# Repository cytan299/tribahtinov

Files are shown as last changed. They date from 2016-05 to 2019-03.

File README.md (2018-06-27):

<p align="right">Language: English, <a href="translations/README_JA.md">Japanese</a></p>

# A Tri-Bahtinov Mask for Aiding Collimation and Focusing of Schmidt Cassegrain, Ritchey Chretien and Newtonian Telescopes

## Introduction

In my opinion, the Bahtinov mask is one of the most useful inventions
for astrophotography. The traditional use of a Bahtinov mask is for
focusing a telescope only and is not used for collimation of reflector
type telescopes like SCTs, RCs and Newtonians.
For collimating a reflector, the method that is commonly used is the
[Airy disk method](http://www.astrophoto.fr/collim.html). I have found
this method to be quite onerous because

* due to atmospherics at my observation location, I have never been able
to see a really clear diffraction pattern of the defocused star or Airy disk. 
* when I adjust the collimating screws to centre the doughnut hole, my
  judgement is rather arbitrary and not as objective as it should
  be. I think my overly optimistic judgement of the diffraction pattern
  makes this method a collimation challenge for me.

And thus, these two reasons motivated me to create a less judgemental
way for collimation.

## The idea

Since the standard Bahtinov mask is such a useful tool for focusing, I
thought that there must be a way to use it for collimation as
well. My idea when applied to an SCT is as follows:

For an SCT, that is well collimated, I would expect that the path
length travelled by light rays from the primary mirror reflected to
the secondary mirror and then reflected to the image plane should all
be the same. However, if the SCT is not collimated then the light rays
do not all have the same path lengths. The effect is that focus can
only be established at one location on the image plane, while focus is
not achieved at other locations.

Therefore, for an uncollimated SCT, while I can achieve perfect
Bahtinov diffraction spikes with one orientation of the Bahtinov mask,
the diffractions spikes will not be perfect for other
orientations. Thus, in my opinion, the most natural way to
simultaneously measure the focus for different orientations of the
Bahtinov mask is to make a mask that has multiple orientations
already built in.

## Tri-Bahtinov mask

For an SCT, the secondary mirror has three adjustment
screws. Therefore, the most obvious way to me is to have three
Bahtinov masks designed into the mask. Thus, my idea of a
**Tri-Bahtinov mask** that has three Bahtinov masks arranged in a
3-fold symmetric fashion. This symmetry should produce a diffraction
pattern that is also 3-fold symmetric. To check this hypothesis, I
generated the diffraction pattern using the program
[Maskulator](http://www.njnoordhoek.com/?p=376).  The diffraction
pattern from such a Tri-Bahtinov mask is shown below for the design
where the smallest angle between the diffraction spikes is 10
degrees. This simulation confirms my hypothesis that a Tri-Bahtinov
produces a diffraction pattern that has three orientations for
checking the focus.

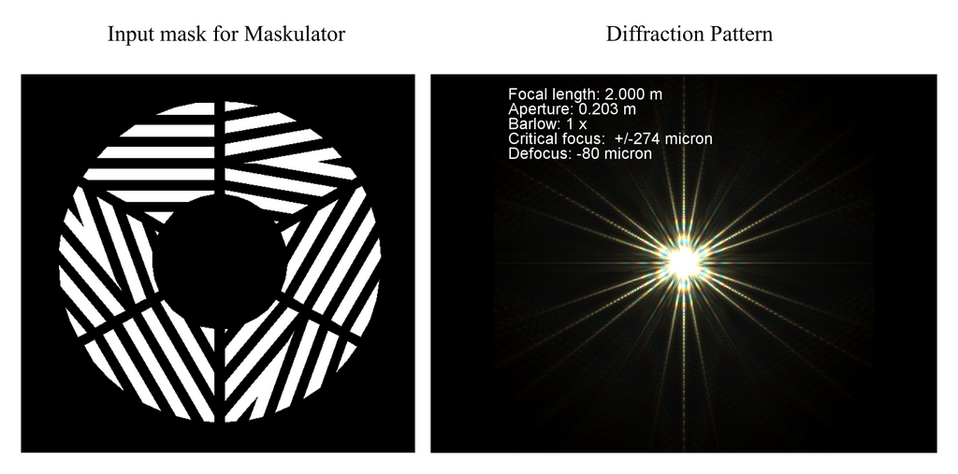
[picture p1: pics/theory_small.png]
Theoretical Diffraction Pattern


## Implementation

I have made a Tri-Bahtinov mask for my 8" LX200 classic which I show below
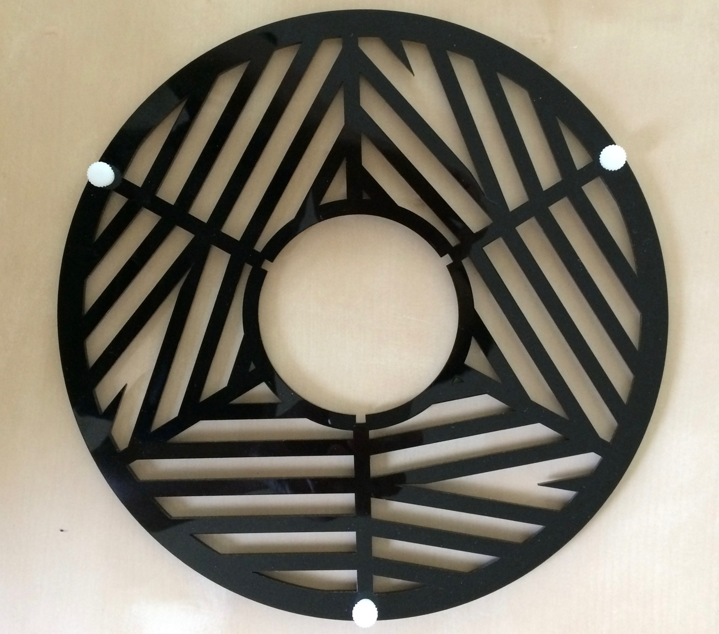
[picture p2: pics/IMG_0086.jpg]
Tri-Bahtinov mask


The Tri-Bahtinov mask is mounted on my LX200 is shown below
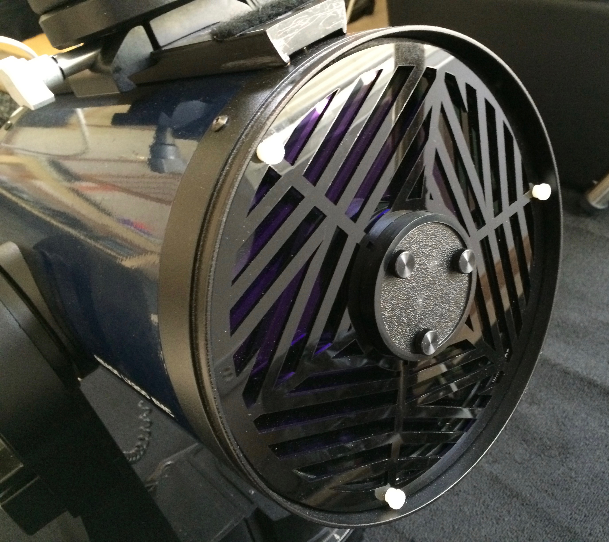
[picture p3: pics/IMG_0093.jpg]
Tri-Bahtinov mask mounted

I have mounted thumb screws on the mask so that when I use it, I orient
these screws to align with the collimation screws on the secondary
mirror. I can then mask one of the three Bahtinov sub-masks to determine which
collimation screw to adjust.

## Improved Tri-Bahtinov mask invented by S. Takagi

S. Takagi has improved the original mask which can be found
[here](http://svg2.mbsrv.net/astro/Tri-Bahtinov_symmetric.html). This
improved mask is more sensitive to any focus errors than the original
mask.

Although I don't show the results of the improved mask here, the
method for using the mask that is outlined in the
[wiki](https://github.com/cytan299/tribahtinov/wiki/A-Tri-Bahtinov-Mask-for-Aiding-Collimation-and-Focusing-of-Schmidt-Cassegrain-Telescopes)
is still applicable.

## Results

My as found diffraction pattern when I point my LX200 at Polaris,
magnified 400x and integrated for 0.5 seconds for the diffraction
pattern of the defocused star and 4
seconds for the Tri-Bahtinov are shown below
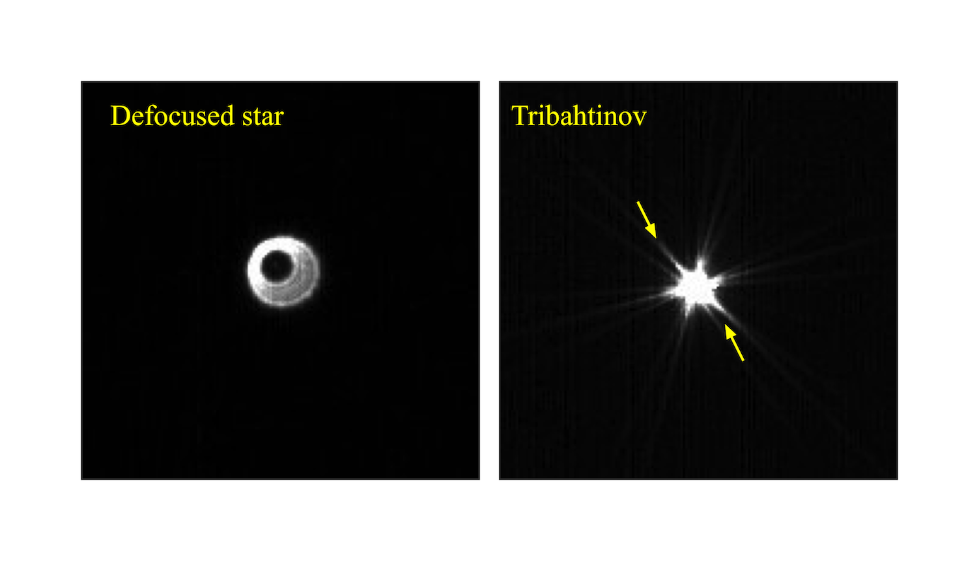
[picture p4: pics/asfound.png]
Pattern as found

It is clear that my LX200 is badly mis-collimated from the 
diffraction pattern. For the Tri-Bahtinov diffraction pattern, I can
get two directions that are close to focus but in one Bahtinov spike orientation,
indicated in the picture, is clearly not in focus. In fact, this orientation is in the
same direction that the donut shadow that is also off-centered.

After using the collimation screws to move the diffraction pattern to the center
and using the Tri-Bahtinov mask to fine tune each orientation, I got 
my LX200 to be very well collimated (might still be a smidgen off from perfection)
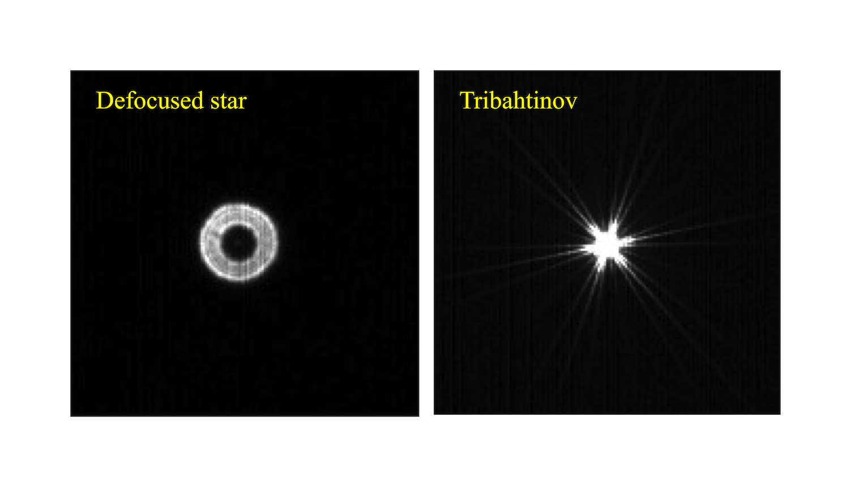
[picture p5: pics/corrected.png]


Thus, my collimation exercise with the Tri-Bahtinov mask allowed
me to achieve collimation with minimal arbitrariness. This is the goal
that I wanted!

## Use on RCs and Newtonians

The contribution from the community at Cloudy Nights has been
tremendous! I had only thought of using the Tri-Bahtinov on my SCT,
but users like Richard (alias "frantolmy") and Satoru Takagi (alias
"Psittacula") have shown that the Tri-Bahtinov also works on RCs and
Newtonians. Please see their posts
[here](https://www.cloudynights.com/topic/536410-a-tri-bahtinov-mask-for-sct-collimation-and-focusing/)

## Tri-Bathinov Grabber

K. Evans' has created a [Tri-Bahtinov
Grabber program](https://github.com/1CM69/Tri-Bahtinov_Grabber) to
objectively help with focusing and collimation.

## Directory structure

* **ponoko** My Tri-Bahtinov mask that can be sent to
[Ponoko](http://www.ponoko.com) to be laser cut.
* **other_formats** My Tri-Bahtinov mask in other formats so that you
  can print it out or edit it. 
* **pics** Image files for this repository.
* **maskulator_movie** directory that contains the avi movie from
  maskulator that shows how the Tri-Bahtinov diffraction pattern
  changes when the focusing changes.
* **python** My python script
  for generating my Tri-Bahtinov mask for any telescope. Please see
  the README.md file in that directory for instructions how to install
  the required python libraries in order for _generate.py_ to work.
* **releases** For most users, you will download the executables for
  _Mac OS X_ and _Windows_ in the
  [releases](https://github.com/cytan299/tribahtinov/releases)
  directory.
* **cover_generator** The cover generators written in python that are
  useful when used in conjunction with K. Evans' [Tri-Bahtinov
Grabber program](https://github.com/1CM69/Tri-Bahtinov_Grabber). 
* **pre-made** There are pre-made masks in _svg_ format for some popular telescopes.
* **translations** Documents translated into languages other than
English are stored.

## How to use the mask

I have written the instructions for using the mask in the
[wiki](https://github.com/cytan299/tribahtinov/wiki/A-Tri-Bahtinov-Mask-for-Aiding-Collimation-and-Focusing-of-Schmidt-Cassegrain-Telescopes).

Satoru Takagi has posted instructions for collimating a Newtonian 
[here](https://www.cloudynights.com/topic/536410-a-tri-bahtinov-mask-for-sct-collimation-and-focusing/page-4). I
have reproduced his instructions in the [wiki](https://github.com/cytan299/tribahtinov/wiki/A-Tri-Bahtinov-Mask-for-Aiding-Collimation-and-Focusing-of-Schmidt-Cassegrain-Telescopes).

## Discussion group

There is an active discussion group that the I monitor. You can post
to
[Cloudy Nights::Equipment::A Tri-Bahtinov mask for SCT collimation and focusing](https://www.cloudynights.com/topic/536410-a-tri-bahtinov-mask-for-sct-collimation-and-focusing/)
to get community help.

## A Tri-Bahtinov mask generator on the web

Here's the link to a Tri-Bahtinov mask generator that is written by
Satoru Takagi:

[Satoru Takagi's Tri-Bahtinov mask generator](http://svg2.mbsrv.net/astro/Tri-Bahtinov.html)

Thanks to Satoru Takagi, you can use his webapp to generate the mask rather
than download and install my program to do this.

## Acknowledgements

I would like to thank Satoru Takagi (25 Jul 2017) for his contributions for
improving _generate.py_. His contributions added the following options
for the user:

* setting the stem width
* setting the ratio between the slit and stem widths.

Satoru has also invented an improved version of the Tri-Bahtinov which
can be found
[here](http://svg2.mbsrv.net/astro/Tri-Bahtinov_symmetric.html).

Ever since publication of the Tri-Bahtinov mask, the support from the
community has been fantastic. For example, K. Evans has created a [Tri-Bahtinov
Grabber program](https://github.com/1CM69/Tri-Bahtinov_Grabber) to
objectively help with focusing and collimation. As part of the support
for this program, I have written python cover generators for both the
original and improved Tri-Bahtinov masks.

## Copyright

All the documentation, pictures, movies and design that I have here is
copyright 2016 C.Y. Tan and released under Creative Commons
Attribution-ShareAlike 3.0 Unported License.

All software is released under GPLv3

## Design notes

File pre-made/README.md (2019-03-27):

# Some pre-made masks

Here are some pre-made masks that may be useful to you. 

## Files for laser cutting

* **C925_Fastar.svg**: is a file created by K. Evans that contains
notches that can be slid over the pins on the C9.25 and then rotated to
align with the collimation screws.
* **LX200-8inch.svg**: is for the LX200 8 inch classic SCT.
* **ETX125.svg**: is for the ETX125. Note line width is 0.01" required
for Ponoko laser cuts. Zoom in to see the mask.

You can remove the copyright and license by deleting the _Copyright_
layer with _Inkscape_ prior to laser cutting.

## Files for 3D printing

* **c11.stl**: is for the Celestron C11 EdgeHD. You should make sure
  that the scaling that you set for the 3D printer should give 300 mm
  for the outside diameter.

## Copyright

The copyright of all the designs here are held by their respective
creators and are released under Creative Commons-ShareAlike 3.0 or 4.0
Unported Licenses.

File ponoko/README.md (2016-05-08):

# The Ponoko manufacture file

The _tribatinov.svg_ file contains the design file that can be sent to
[Ponoko](http://www.ponoko.com) to be laser cut. This design is for
the 8" classic Meade LX200 telescope. The svg file can be read with
[Inkscape](https://inkscape.org/en/) and using Inscape It should be
relatively easy to rescale and edit the design for other telescope sizes.

I have chosen the smallest angle between the diffraction spikes to be
10 deg. in this design.

To see the design, you must zoom in because the stroke width is 0.01
mm as required by Ponoko. You have to delete the Copright layer before
sending to Ponoko as well. The material that I have chosen for the mask is 3
mm Black Acrylic in P2 size.

A drawing of my design is shown here
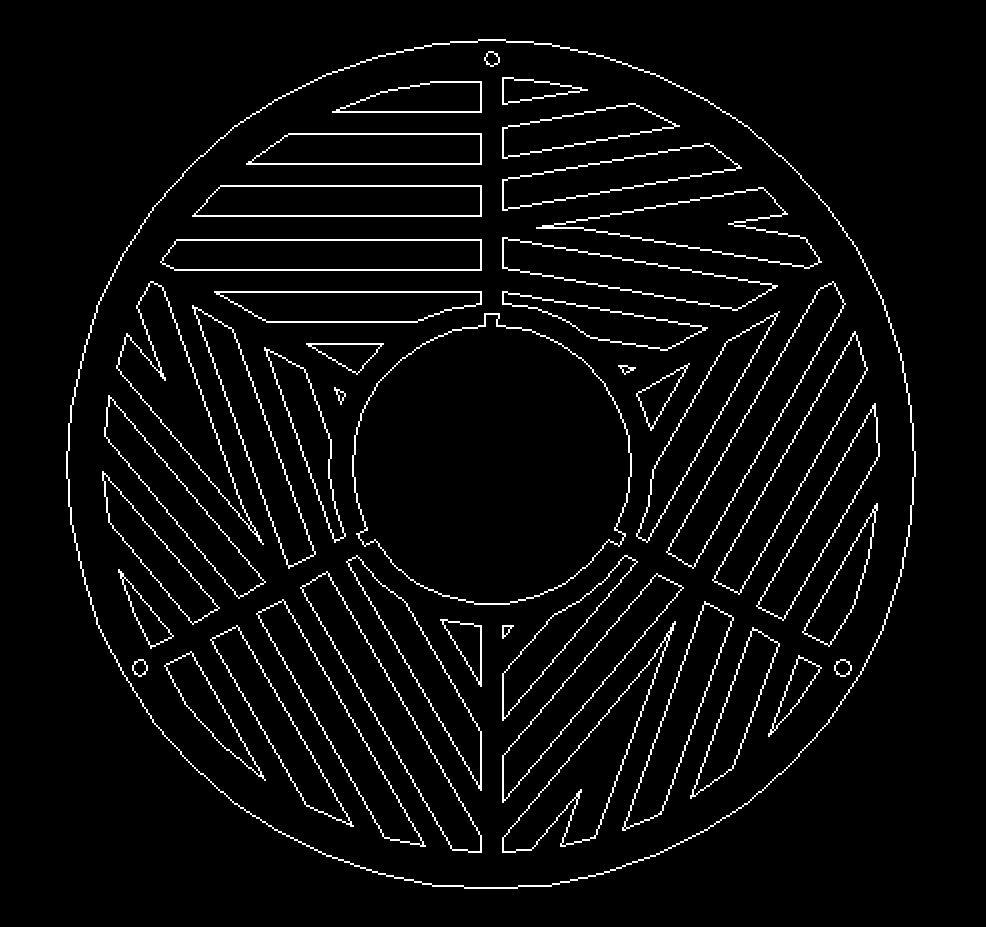
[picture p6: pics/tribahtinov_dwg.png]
Tri-Bahtinov drawing


Other formats for the Tri-Bahtinov mask can be found in the
[other formats](https://github.com/cytan299/tribahtinov/blob/master/other_formats) directory.

## Copyright

This design is copyright 2016 C.Y. Tan and released under Creative Commons
Attribution-ShareAlike 3.0 Unported License.

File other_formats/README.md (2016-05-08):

# Other formats

Here are other formats of the Tri-Bahtinov mask that might be useful
for you to modify and print.

* **tribahtinov.pdf** PDF format of the mask. This is readable with Acrobat Reader.
* **tribahtinov.eps** Encapsulated postscript. This is readable with ghostscript.
* **tribahtinov.dwg** DWG file that is readable with Autocad.
* **tribahtinov.dxf** DXF file that is readable with many CAD programs like LibreCad.

All the files contain a 1 inch square drawing so that you can check the size of your printout matches what I intend the size of the Tri-Bahtinov mask to be.

## Copyright

All the design files here are copyright 2016 C.Y. Tan and released
under Creative Commons Attribution-ShareAlike 3.0 Unported License.

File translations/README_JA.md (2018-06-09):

<p align="right">Language: <a href="../README.md">English</a>, Japanese</p>

# トライ・バーティノフマスク：シュミットカセグレン、リッチークレチアン及びニュートン式望遠鏡の光軸合わせとピント合わせ支援ツール

## 前書き

バーティノフマスクは天体写真にとって最も有用な発明の1つだと思います。ただしバーティノフマスクの元々の用途は望遠鏡のピント合わせ用であり、シュミットカセグレン(SCT)、リッチークレチアン(RC)、ニュートン式等の反射望遠鏡の光軸調整用ではありません。 一方、反射望遠鏡の光軸合わせには[エアリーディスク法](http://www.astrophoto.fr/collim.html)が一般的に使用されます。しかし私はこの方法が以下の理由により非常に難しいものだと思いました。 

* 私の観測場所のシーイングの制約により、本当にクリアなエアリーディスクを私は見たことがありません。 
* 光軸調整ネジを調整して像のドーナツの穴が中心に合ったことを判断するとき、私の判断はむしろ主観的で、客観的とはいえません。 そして、エアリーディスクパターンに対し私が楽観的な判断をしてしまうため、この方法に頼った光軸調整は私にとって難題でした。 

これら2つの理由が、私にコリメーションのための個人の判断力をあまり必要としない方法を作り出す動機となりました。 

## アイデア

標準的なバーティノフマスクはピント合わせのための便利なツールなので、完全な合焦の前提となる光軸合わせのためにも使用できる方法になるはずだと私は考えました。SCTの光軸合わせのための私の考えは以下になります。

完全に光軸が合ったSCTでは、主鏡からの光線が副鏡に反射し、焦点面に投影される光線の光路長はすべて同じでなければならないと思われます。 しかし、SCTの光軸が合っていない場合、光線はすべてで同じ光路長にはならないでしょう。 その効果は、ある場所での焦点だけが合い、他の場所では焦点が合わないことになるでしょう。 

したがって、光軸が合っていないSCTでは、バーティノフマスクの1つの向きでだけ焦点が合った完全な回折像が現れますが、他の方向に対しては焦点の合っていない像が現れるでしょう。 バーティノフマスクを回転させ、すべての向きで完全な回折像が現れれば光軸が合っていることになるわけです。したがって、異なる向きの合焦を同時にバーティノフマスクで確認する最も自然な方法は、複数の向きのバーティノフマスクが組み込まれているマスクを作成することです。 

## トライ・バーティノフマスク

SCTの場合、副鏡には3本の調整ネジがあります。 したがって、最も明快な方法は3つのバーティノフマスクを配置したマスクを設計することだと私は考えました。 したがって、トライ・バーティノフマスクと名付けたこのマスクは、3つのバーティノフマスクを三回対象の回転対称に並べたものです。 この対称性はまた、三回対象の回転対称の回折パターンを生成するはずです。 この仮説を確認するために、私は[Maskulator](http://www.njnoordhoek.com/?p=376)プログラムを使用して回折パターンをシミュレーションしました 。 回折スパイクの角度が10度になるように設計されたトライバーティノフマスクからの回折パターンを以下に示します。 このシミュレーション結果は、合焦を確認するためのトライ・バーティノフマスクは3方向の回折パターンを発生するという私の仮説を裏付けています。 

Theoretical Diffraction Pattern

## 実装

以下のような8インチLX200クラシック用のトライ・バーティノフマスクを作りました
Tri-Bahtinov mask

私のLX200に取り付けたトライ・バーティノフマスクの様子は以下の通りです。
Tri-Bahtinov mask mounted
私はマスクにつまみネジを取り付けました。マスクを使用するとき、副鏡の光軸合わせのネジとこのネジの付いている方向を一致させます。また、どの光軸調整ネジを使って調整すれば良いのかは、3つのバーティノフマスクのうちの対象となる一つを（手などで）遮ることで知ることができます。

## 結果

私のLX200で、400倍に拡大した北極星を用いて得た回折パターンは以下の通りです。エアリーディスクは0.5秒、トライ・バーティノフマスクは4秒の露出をかけています。
Pattern as found
エアリーディスク回折パターンから、私のLX200は光軸が合っていないことが明らかです。  トライ・バーティノフマスクの回折パターンでは、2つの方向はほぼ合焦していることを確認できますが、残りの1つのバーティノフスパイクの様子は、明らかに焦点が合っていないことを示しています。 この方向はエアリーディスクのドーナツの影の中心から外れている方向と一致しています。 

光軸調整ネジを使用してエアリーディスクの影を中央に移動させ、さらにトライ・バーティノフマスクを使用して各方向を微調整した後、私のLX200はよく光軸が合いました。（ただしまだ完璧に光軸が合った状態ではないかもしれません）
Pattern as found

このように、私はトライ・バーティノフマスクを用いた光軸合わせ作業により、主観的な判断を最小化した光軸合わせを達成できました。これが私が望んでいた目標です！

## RCとニュートン鏡筒での使用

Cloudy Nightsのコミュニティからの貢献は素晴らしいです！
私は元々SCTでのトライバーティノフマスク使用しか考えていませんでしたが、Richard (ハンドル名"frantolmy")や Satoru Takagi (ハンドル名"Psittacula")などの人たちがトライバーティノフマスクはRCやニュートン鏡筒でも使えることを示しました。彼らの投稿は[こちら](https://www.cloudynights.com/topic/536410-a-tri-bahtinov-mask-for-sct-collimation-and-focusing/)にあります。

## ディレクトリ構造

* **ponoko** [Ponoko](http://www.ponoko.com)でレーザーカットするたのトライ・バーティノフマスクのデータ
* **other_formats** 他のフォーマットのトライ・バーティノフマスクデータ。印刷や編集できます。
* **pics** このリポジトリの画像ファイル
* **maskulator_movie** フォーカスの変化とともに、トライ・バーティノフマスク回折パターンがどのように変化するかを示すmaskulatorによるシミュレーションのaviムービー
* **python** 様々な望遠鏡のためのトライ・バーティノフマスクを生成するための私が開発したpythonスクリプト。  generate.pyを動作させるために必要なPythonライブラリをインストールする方法については、そのディレクトリにあるREADME.mdファイルを参照してください。
* **releases** generate.pyを実行したい多くのユーザのためのMac OS XおよびWindows用実行可能ファイルは[releases](https://github.com/cytan299/tribahtinov/releases)ディレクトリにあります。
* **translations** 翻訳された文書があります。

## マスクの使い方

[こちら](HowToUse_JA.md)にマスクを使用するための説明書があります。 

Satoru Takagiは、ニュートン鏡筒での光軸調整方法を[ここ](https://www.cloudynights.com/topic/536410-a-tri-bahtinov-mask-for-sct-collimation-and-focusing/page-4)に投稿しました。またその説明を[こちら](HowToUse_JA.md)にも掲載します。

## 電子掲示板

以下の電子掲示板で活発にディスカッションされています。私もモニターしています。有用な情報を投稿ください。[Cloudy Nights::Equipment::A Tri-Bahtinov mask for SCT collimation and focusing](https://www.cloudynights.com/topic/536410-a-tri-bahtinov-mask-for-sct-collimation-and-focusing/)

## ウェブブラウザで使えるトライ・バーティノフマスク作図ソフト

Satoru Takagiが作成したトライ・バーティノフマスク作図ソフトを以下に紹介します。

[Satoru Takagi's Tri-Bahtinov mask generator](http://svg2.mbsrv.net/astro/Tri-Bahtinov.html)

彼の開発したwebappを使うことで、generate.pyをダウンロード・インストールしなくても、様々な望遠鏡のためのマスクの図面を得ることができます。 

## 謝辞:

私はSatoru Takagiによる _generate.py_ の改良に感謝します。彼は以下のカスタマイズ機能を追加しました。
* ステムの幅
* スリットとステムの比率

## コピーライト

ここにあるドキュメンテーション、写真、ムービー、デザインはC.Y. Tanが著作権を持ちます。Copyright 2016 by C.Y. Tan.　それらは、Creative Commons Attribution-ShareAlike 3.0 Unported Licenseの下で公開されます。 また、すべてのソフトウェアはGPLv3でリリースされます。

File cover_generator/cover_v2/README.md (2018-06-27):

# Python script for generating a cover for the improved Tri-Bahtinov Mask 

This directory contains the source code of _cover_v2_ that I have
written in python for generating a Tri-Bahtinov mask cover for
S. Takagi's improved Tri-Bahtinov mask. To make a cover for the
original Tri-Bahtinov mask use _cover_v1_.

This cover is used for covering two of the three Bahtinov
patterns. The cover is to make it easy to use K. Evans' [Tri-Bahtinov
Grabber program](https://github.com/1CM69/Tri-Bahtinov_Grabber).

## Executing cover_v2.py

The python version has to be version 2.7.x

I use [cairo](https://cairographics.org/) graphics for generating the
tribahtinov mask cover, you will have to download and install graphics
libraries that I list below. Since I develop on the Mac, I cannot
guarantee that the instructions below are 100% correct for other
platforms.

### Required libraries

The necessary libraries and python programs necessary to get
the _cover_v2.py_ to work are detailed below. I've divided them into two
sections for _Mac  OS X_ and _Windows_.

#### Mac OS X

* **pip** This python script is necessary for installing the cairocffi
library. On _Mac OS X_, do the following:
```
sudo easy_install pip
```
For _Linux_,  (I cannot test this, because I don't run _Linux_), 
the pip python script can be downloaded from
[here](https://pip.pypa.io/en/stable/installing/). It is installed using
```
python get-pip.py
```
* **cairocffi** For my python script to work, it is necessary to
  install the [cairocffi](https://github.com/SimonSapin/cairocffi)
  library. Do the following to install it:
```
  sudo -H pip install cairocffi
  ```
* **cairo** Finally, you have to install
[macports][http://www.macports.org] and then install _cairo_
```
sudo port install cairo
```

#### Windows
It is a lot more involved for getting _generate.py_ to run in
_Windows_.

* **python** (Python)[https://www.python.org/downloads/] must be
  installed. I use version 2.7.10 which is the version that also comes
  with _Mac OS X_. 
* **pip** _pip_ comes with the the _python_ installation.
* **Microsoft Visual C++ Compiler for Python 2.7** Before installing
  _cairocffi_, you must also have installed. You can download it
  [here](https://www.microsoft.com/en-us/download/details.aspx?id=44266).
* **cairocffi** _cairocffi_ can be installed using
```
python install cairocffi
```
* **cairo** _cairo_ must be downloaded from
  [here](http://ftp.gnome.org/pub/GNOME/binaries/win64/gtk+/2.22/gtk+-bundle_2.22.1-20101229_win64.zip). Unzip
  and rename the root directory in the zip file to _c:\GTK_.
  
## Running cover_v2.py

To run _cover_v2.py_, you can do the following:
```
python cover_v2.py
```
## The result

Here is a typical result of the cover that covers 2 of the 3 Bahtinov patterns.

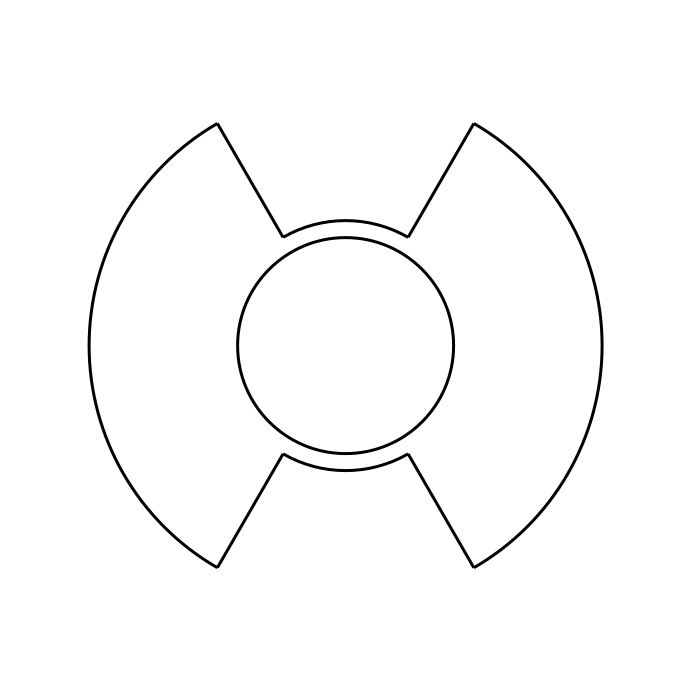
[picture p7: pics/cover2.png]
Tri-Bahtinov mask cover


## Copyright

The software that is written by the author is copyright 2018 C.Y. Tan
and released under GPLv3.

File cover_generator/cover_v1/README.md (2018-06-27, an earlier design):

# Python script for generating a cover for the original Tri-Bahtinov Mask 

This directory contains the source code of _cover_v1_ that I have
written in python for generating a Tri-Bahtinov mask cover for the original
Tri-Bahtinov mask. To make a cover for S. Takagi's improved version of
the Tri-Bahtinov mask use _cover_v2_.

This cover is used for covering two of the three Bahtinov
patterns. The cover is to make it easy to use K. Evan's [Tri-Bahtinov
Grabber program](https://github.com/1CM69/Tri-Bahtinov_Grabber).

## Executing cover_v1.py

The python version has to be version 2.7.x

I use [cairo](https://cairographics.org/) graphics for generating the
tribahtinov mask cover, you will have to download and install graphics
libraries that I list below. Since I develop on the Mac, I cannot
guarantee that the instructions below are 100% correct for other
platforms.

### Required libraries

The necessary libraries and python programs necessary to get
the _cover_v1.py_ to work are detailed below. I've divided them into two
sections for _Mac  OS X_ and _Windows_.

#### Mac OS X

* **pip** This python script is necessary for installing the cairocffi
library. On _Mac OS X_, do the following:
```
sudo easy_install pip
```
For _Linux_,  (I cannot test this, because I don't run _Linux_), 
the pip python script can be downloaded from
[here](https://pip.pypa.io/en/stable/installing/). It is installed using
```
python get-pip.py
```
* **cairocffi** For my python script to work, it is necessary to
  install the [cairocffi](https://github.com/SimonSapin/cairocffi)
  library. Do the following to install it:
```
  sudo -H pip install cairocffi
  ```
* **cairo** Finally, you have to install
[macports][http://www.macports.org] and then install _cairo_
```
sudo port install cairo
```

#### Windows
It is a lot more involved for getting _generate.py_ to run in
_Windows_.

* **python** (Python)[https://www.python.org/downloads/] must be
  installed. I use version 2.7.10 which is the version that also comes
  with _Mac OS X_. 
* **pip** _pip_ comes with the the _python_ installation.
* **Microsoft Visual C++ Compiler for Python 2.7** Before installing
  _cairocffi_, you must also have installed. You can download it
  [here](https://www.microsoft.com/en-us/download/details.aspx?id=44266).
* **cairocffi** _cairocffi_ can be installed using
```
python install cairocffi
```
* **cairo** _cairo_ must be downloaded from
  [here](http://ftp.gnome.org/pub/GNOME/binaries/win64/gtk+/2.22/gtk+-bundle_2.22.1-20101229_win64.zip). Unzip
  and rename the root directory in the zip file to _c:\GTK_.
  
## Running cover_v1.py

To run _cover_v1.py_, you can do the following:
```
python cover_v1.py
```
## The result

Here is a typical result of the cover that covers 2 of the 3 Bahtinov patterns.

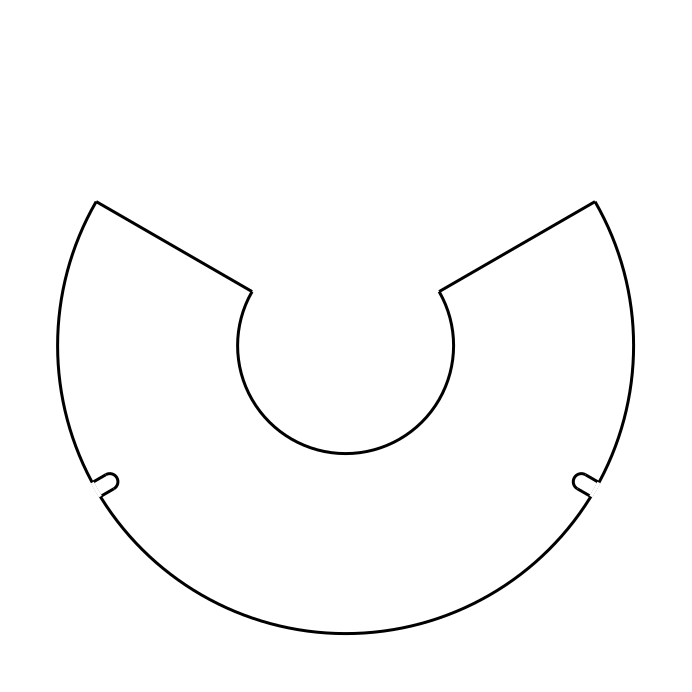
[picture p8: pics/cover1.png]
Tri-Bahtinov mask cover


## Copyright

The software that is written by the author is copyright 2018 C.Y. Tan
and released under GPLv3.

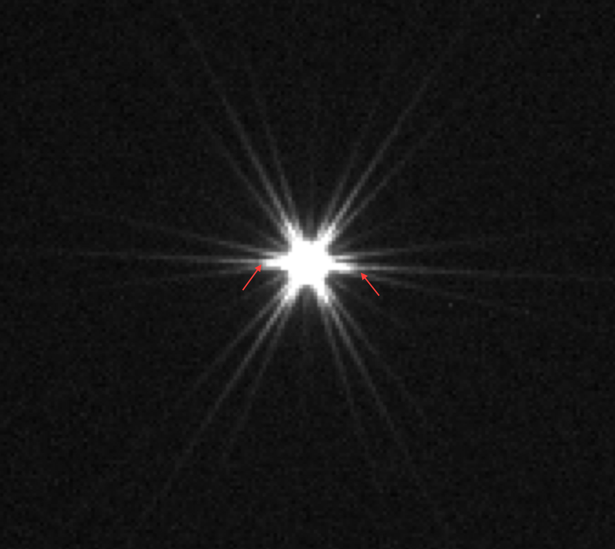
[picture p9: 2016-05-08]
pics/as_found.png

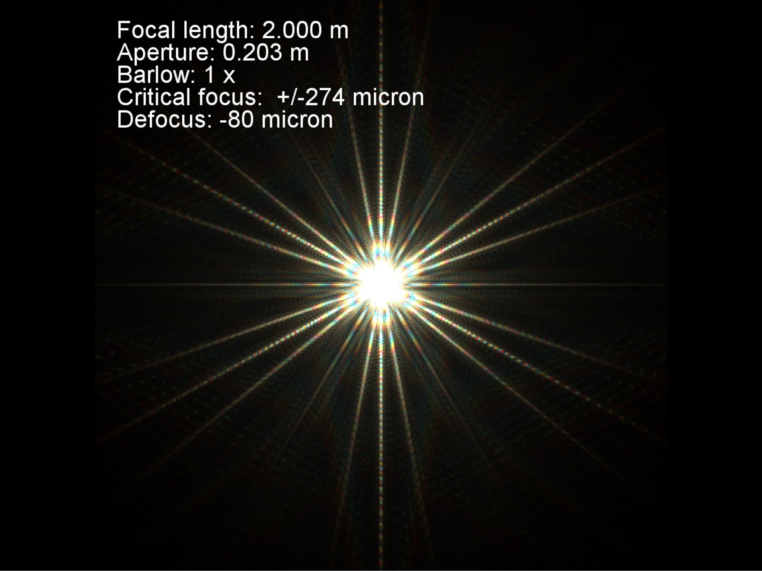
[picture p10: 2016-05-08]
pics/maskulator.png

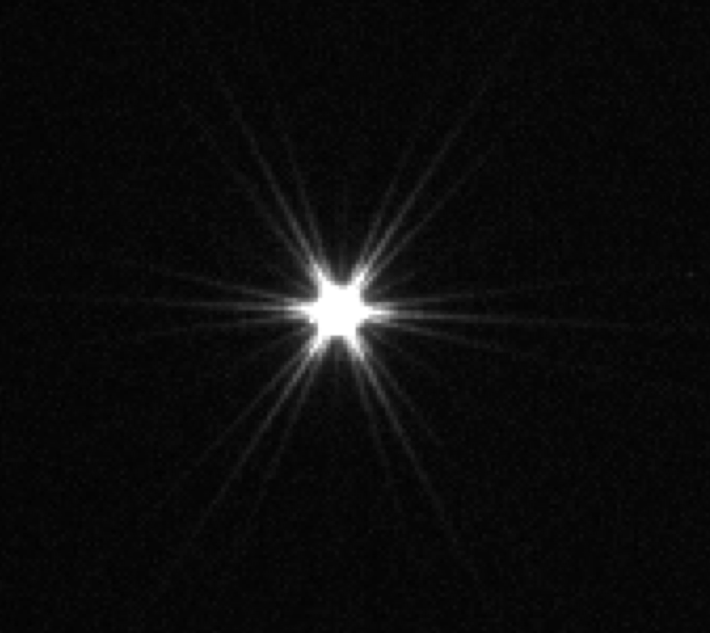
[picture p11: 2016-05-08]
pics/collimated.png

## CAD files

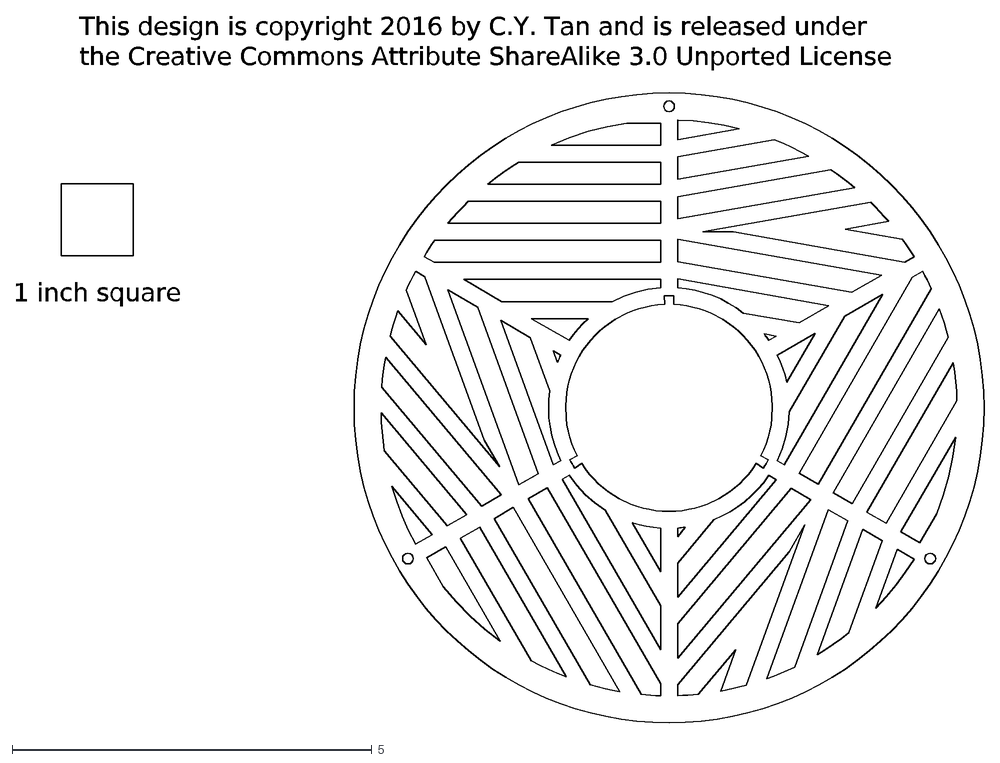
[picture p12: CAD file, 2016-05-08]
other_formats/tribahtinov.dxf
This design is copyright 2016 by C.Y. Tan and is released under
the Creative Commons Attribute ShareAlike 3.0 Unported License
1 inch square

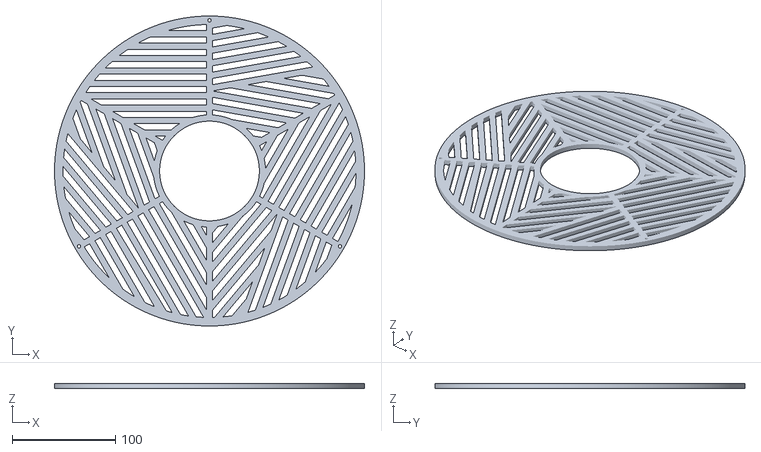
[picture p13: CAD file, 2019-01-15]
pre-made/c11.stl
300.0 x 300.0 x 5.00

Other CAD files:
other_formats/tribahtinov.dwg

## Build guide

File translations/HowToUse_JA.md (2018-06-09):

# トライ・バーティノフマスク:シュミットカセグレン望遠鏡の光軸合わせとピント合わせ支援のためのツール

## 前書き 

標準的なバーティノフマスクは天体写真で用いらるれ焦点合わせのための最も有用なツールの1つです。 しかし、それを三回対象にすること、すなわち2つの別の方向を向いたバーティノフマスクパターンをマスクに追加することで、もっと有用になると考えます。 それが「トライ・バーティノフマスク」と私が名付けたものです。  トライ・バーティノフマスクでは、シュミットカセグレン望遠鏡(SCT)の光軸がよく合っているかどうかをチェックする機能が追加されます。 以下は、任意のサイズのトライ・バーティノフマスクを生成する方法、およびそれを用いて光軸調整を行うための説明書です。 

## Satoru Takagiのwebappを使ってトライ・バーティノフマスクを生成する 

webAppにより、*generate*をインストールせずにブラウザからマスクを生成することができます。 彼のTri-Bahtinovマスクジェネレータへのリンクは以下のとおりです。 

 [Satoru Takagiのトライ・バーティノフマスクジェネレータ](http://svg2.mbsrv.net/astro/Tri-Bahtinov.html)

## ダウンロードしたプログラムてトライ・バーティノフマスクを生成する 

 トライ・バーティノフマスクは、 [リリースディレクトリ](https://github.com/cytan299/tribahtinov/releases)内の実行可能ファイルを使用して生成できます。*generate*をインストールするための説明書に従ってください。 

### マスク生成に必要な入力パラメータ (上記いずれの方法にも共通)

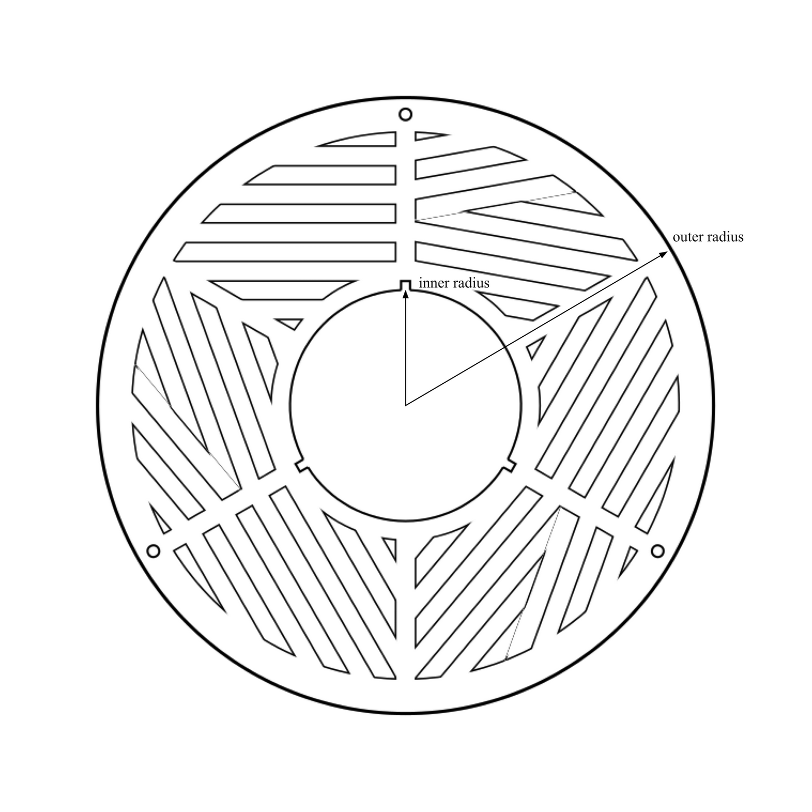
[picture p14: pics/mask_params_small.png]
入力半径の説明図


必要なパラメータは次のとおりです。 
* **focal length**(望遠鏡の焦点距離[mm]) ： スリットの数を多くしたり少なくしたりしたい場合、実際の焦点距離に対して入力する焦点距離を調節してください。 
* **outer radius**(マスクの外径[in] (webAppでは[mm]も選択可))： 望遠鏡の対物開口部内にマスクが入るように設定します。 
* **inner radius**(マスクの内径[in] (同上))： 光軸調整ネジにアクセスできるよう、副鏡セルをかわすように設定します。 

生成されるマスクは、3つのグラフィックス形式で提供されます。 
* **tribahtinov.pdf** pdf形式のtribahtinovマスク 
* **tribahtinov.png** png形式のtribahtinovマスク 
* **tribahtinov.svg** tribahtinovマスク（svg形式） （WebAppではこの形式のみサポート）

上記のマスク図面は、以下のパラメータで*generate*によって生成された例です 
* **focal length**(焦点距離): 1000mm
* **outer radius**(外径): 4インチ
* **inner radius**(内径): 1.5インチ

注：*generate*やwebAppで作成されるマスクに不要部分があります。 これは手で簡単に消去することができます。 

### 回折パターンのマスク・ムービー

[Maskulator](http://www.njnoordhoek.com/?p=376)によるシミュレーションで生成されたマスク振る舞いを確認できます。 このプログラムでは、フォーカスが変わると回折パターンがどのように変化するかを確認することができます。 作成したマスクと*Maskulator*で計算した回折パターンの例を下に示します。

Maskulatorの例

*Maskulator*は、フォーカシングの際に回折パターンがどのように変化するかを示すムービーを生成することもできます。 

[Makulatorムービー ](../maskulator_movie/maskulator.mpeg)

## SCTとRCでトライバーティノフマスクを使用する
* マスクを使用する前にエアリーディスクが概ね中央にあることを確認します。下に示すように、ドーナツの中心がかなりずれている（光軸が大幅にずれている）ことがあります 

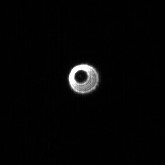
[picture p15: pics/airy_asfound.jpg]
Uncollimated


このような場合は、マスクを使用するより焦点を外したエアリディスクを見て影が中央に配置されるようにまずは調整する方が効率的です。 

エアリディスクが概ねもしくはしっかりと中心に合うようになったら、
* マスクのノッチまたは白いつまみネジを光軸調整ネジに合わせて、マスクを対物開口部に設置します。 
マスク設置状態
* 適当な紙などで3つのバーティノフマスクの一つの部分を覆うと、光条が陰るのを観察することで、どの光軸調整ネジがどの光条に対応するのかを確認します。
* 3方向のバーティノフ回折パターンのうちの1つに着目し、それが合焦した状態になるよう**合焦ノブで**調節します。 これを基準バーティノフ回折パターンと呼ぶことにします。 この段階で、おそらく他の2つの方向の回折パターンは合焦していない状態にあることを示しているでしょう。 
* 他の2つのバーティノフ回折パターンの方向に対応する**光軸調整ネジ**を使用して、それらが合焦するように調整します。 ここで、対応する調整ネジは、前のステップで指の影のテストによって決定されたものを用います。 
* 必要に応じて、基準バーティノフ回折パターンが完全に合焦するようにSCTの**合焦ノブで**再度調節します。さらに、満足いく結果が得られるまで、他の2つのバーティノフ回折パターンで前のステップを繰り返し、3方向の回折パターン全てが完全に合焦を示すよう調整します。 

コリメート状態

## ニュートン鏡筒でトライバーティノフマスクを使用する (S.Takagi)
この方法は、S. Takagiの[Cloudy Nights](https://www.cloudynights.com/topic/536410-a-tri-bahtinov-mask-for-sct-collimation-and-focusing/page-4)への投稿を引用したものです。
* 他の光軸調整ツールで初期的な光軸調整を実施します。
    * 例えば、レーザーコリメータを使う場合、主鏡の中心に光点が到達するように副鏡を調整します。次に主鏡を反射したレーザー光がレーザーコリメータの中心に戻ってくるように概ね主鏡を調整します。
* 既存の光軸調整ツールを取り外し、トライバーティノフマスクを設置します。このとき、マスクのマークと主鏡の光軸調整ネジの方向が一致するようにします。副鏡のではありません。
* テスト用の星を視野の中心に導入しピントを合わせます。なお、光軸の状態を評価するとき、テスト用の星は常に視野の中心にあるようにします。これはSCTの場合と同様です。
* 以後のトライバーティノフマスクを用いた光軸合わせは、主鏡の調整ネジのみを用いて行います。
* 主鏡の光軸調整ネジと回折像の関係はSCTと同様になると思いますので、SCTの調整法と同様に調整を行います。

## バグレポートと提案
あなたはバグや提案を[issuesタブ](https://github.com/cytan299/tribahtinov/issues)から投稿することができます。

## 著作権 

私が書いたすべてのソフトウェア、ドキュメント、ハードウェアはC.Y. Tanが著作権を持ちます。Copyright 2016 by C.Y. Tan. それらすべてのソフトウェアはGPLv3でリリースされます。またドキュメントはCreative Commons Attribution-ShareAlike 3.0 Unported Licenseで公開されます。

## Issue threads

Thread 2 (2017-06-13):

Always equalize the area of slits of upper right and lower right.

satakagi, 2017-06-13:
I have created a function to calculate the boundary line which makes the area of upper right slits equal to the area of lower right slits. This page determines its boundary by this function.
[http://svg2.mbsrv.net/astro/Tri-Bahtinov_r2a.html](http://svg2.mbsrv.net/astro/Tri-Bahtinov_r2a.html)

I also placed a checkbox for the function to build mount holes and the function to equalize the width of boundary stems and slits. I would like to release it after allowing the original boundary calculation logic to be selected. Are these features meaningful?

cytan299, 2017-06-13:
Hi Satoru,   Those are great ideas! One option, I think might be useful is for the user to select the width of the stem rather than to making them equal. You can have equal slit width and stem width as the default when this option is selected. i.e.         slit width to stem width ratio = 1:1
as defaultand then the user can enter for example:       slit width to stem width ratio = 1.5:1
What do you think?
cytan

      From: Satoru Takagi <notifications@github.com>
 To: cytan299/tribahtinov <tribahtinov@noreply.github.com>
Cc: Subscribed <subscribed@noreply.github.com>
 Sent: Tuesday, June 13, 2017 9:16 AM
 Subject: [cytan299/tribahtinov] Always equalize the area of slits of upper right and lower right. (#2)

I have created a function to calculate the boundary line which makes the area of upper right slits equal to the area of lower right slits. This page determines its boundary by this function.
http://svg2.mbsrv.net/astro/Tri-Bahtinov_r2a.htmlI also placed a checkbox for the function to build mount holes and the function to equalize the width of boundary stems and slits. I would like to release it after allowing the original boundary calculation logic to be selected. Are these features meaningful?—
You are receiving this because you are subscribed to this thread.
Reply to this email directly, view it on GitHub, or mute the thread.

satakagi, 2017-06-14:
Hi, cytan.
Thanks for your comment. I just completed coding and simple testing!
[http://svg2.mbsrv.net/astro/Tri-Bahtinov_r2a.html](http://svg2.mbsrv.net/astro/Tri-Bahtinov_r2a.html)

cytan299, 2017-06-15:
Hi Satoru,   Excellent programming! You are a much better programmer than I am. Looks really good. You should really announce what you did on the forums.  I have no doubt that your work will be a fantastic contribution to the astrophotography community.
cytan

      From: Satoru Takagi <notifications@github.com>
 To: cytan299/tribahtinov <tribahtinov@noreply.github.com>
Cc: cytan299 <cytan299@yahoo.com>; Comment <comment@noreply.github.com>
 Sent: Wednesday, June 14, 2017 8:02 AM
 Subject: Re: [cytan299/tribahtinov] Always equalize the area of slits of upper right and lower right. (#2)

Hi, cytan.
Thanks for your comment. I just completed coding and simple testing!
http://svg2.mbsrv.net/astro/Tri-Bahtinov_r2a.html—
You are receiving this because you commented.
Reply to this email directly, view it on GitHub, or mute the thread.

satakagi, 2017-06-15:
Hi, cytan, Thank you for your reply.
I happened to develop WWW technology as a profession and had a hobby of astrophotography, so I just could port your cool ideas and logic as a web application. And I am also pleased that I made a little improvement contribution. Of course, the same open source license declaration is listed in the source code of webApps I ported.

By the way, since I'd like to introduce Tri-Bahtinov mask also to Japanese people, I have translated readme and wiki of this repository which describes its mechanism and usage. I want to issue a pull request to add these translations.

cytan299, 2017-06-15:
Hi Satoru,   Please translate to Japanese. This will help popularize this mask.
   And please feel free to fork my distribution.
cytan

      From: Satoru Takagi <notifications@github.com>
 To: cytan299/tribahtinov <tribahtinov@noreply.github.com>
Cc: cytan299 <cytan299@yahoo.com>; Comment <comment@noreply.github.com>
 Sent: Thursday, June 15, 2017 9:45 AM
 Subject: Re: [cytan299/tribahtinov] Always equalize the area of slits of upper right and lower right. (#2)

Hi, cytan, Thank you for your reply.
I happened to develop WWW technology as a profession and had a hobby of astrophotography, so I just could port your cool ideas and logic as a web application. And I am also pleased that I made a little improvement contribution. Of course, the same open source license declaration is listed in the source code of webApps I ported.By the way, since I'd like to introduce Tri-Bahtinov mask also to Japanese people, I have translated readme and wiki of this repository which describes its mechanism and usage. I want to issue a pull request to add these translations.—
You are receiving this because you commented.
Reply to this email directly, view it on GitHub, or mute the thread.

satakagi, 2017-06-18:
Thank you very much for accepting my pull request immediately! I will introduce it to the Japanese people at once.

Closed 2017-06-18.

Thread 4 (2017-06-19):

The pitch of the diffraction grating becomes thick

satakagi, 2017-06-19:
I noticed that the diffraction grating pitch generated by the webApps version tri-bahtinov mask generator is thicker than the conventional bahtinov mask generator on [this site](http://astrojargon.net/maskgenerator.aspx).

According to the [cloudy nights thread](https://www.cloudynights.com/topic/178843-revolutionary-new-way-of-focusing-no-less/#entry2309839) that that site refers to, the expression that determines the width (pitch) of the diffraction grating is explained as follows.
` s = f / 150`
Where s is the sum of slit and uncut space, f is focal length, 150 is bahtinov factor.

According to the following part of generate.py,
` spacing = (tri_stem_w + tri_w); -> Line 112, 217, 342`
I interpreted that the variable equivalent to s is spacing, the variable equivalent to slit is tri_w, and the variable corresponding to uncut space is tri_stem_w.

The formula for determining the width of the diffraction grating would be:
`spacing = focal_length / BAHTINOV_FACTOR`

On the other hand, according to the following part of generate.py,
`Tri_w = focal_length / BAHTINOV_FACTOR; -> Line 567`
tri_w, rather than spacing, is generated by that expression. As a result, it seems that spacing is calculated to be large by tri_stem_w.

I have not tested it because I can not prepare the python execution environment, but it might be able to fix it by doing as follows.
<pre>
567c567,572
< tri_w = focal_length/BAHTINOV_FACTOR;
---
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
</pre>

cytan299, 2017-06-19:
Hi Satoru,   Hmmm, you might be right. You're the first person to actually check out the code. I'll have a look at it tonight and get back to you.
cytan

      From: Satoru Takagi <notifications@github.com>
 To: cytan299/tribahtinov <tribahtinov@noreply.github.com>
Cc: Subscribed <subscribed@noreply.github.com>
 Sent: Monday, June 19, 2017 6:59 AM
 Subject: [cytan299/tribahtinov] The pitch of the diffraction grating becomes thick (#4)

I noticed that the diffraction grating pitch generated by the webApps version tri-bahtinov mask generator is thicker than the conventional bahtinov mask generator on this site.According to the cloudy nights thread that that site refers to, the expression that determines the width (pitch) of the diffraction grating is explained as follows.
s = f / 150
Where s is the sum of slit and uncut space, f is focal length, 150 is bahtinov factor.According to the following part of generate.py,
spacing = (tri_stem_w + tri_w); -> Line 112, 217, 342
I interpreted that the variable equivalent to s is spacing, the variable equivalent to slit is tri_w, and the variable corresponding to uncut space is tri_stem_w.The formula for determining the width of the diffraction grating would be:
spacing = focal_length / BAHTINOV_FACTOROn the other hand, according to the following part of generate.py,
Tri_w = focal_length / BAHTINOV_FACTOR; -> Line 567
tri_w, rather than spacing, is generated by that expression. As a result, it seems that spacing is calculated to be large by tri_stem_w.I have not tested it because I can not prepare the python execution environment, but it might be able to fix it by doing as follows.567c567,572
< tri_w = focal_length/BAHTINOV_FACTOR;
---
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
—
You are receiving this because you are subscribed to this thread.
Reply to this email directly, view it on GitHub, or mute the thread.

cytan299, 2017-06-20:
Hi Satoru,   I patched generate.py using your diff enclosed in your message. See generate_satoru.py. Unfortunately, the mask that it generates looks like this:

which has slots that are too thin. The input is:
focal length = 1000 mmouter radius = 4 ininner radius = 1.5 in.
Here is the Bahtinov mask generated using the astrojargon bahtinov mask generator:

which was generated with the attached file.
I will try to look at the code more carefully over the weekend.
cytan

      From: Satoru Takagi <notifications@github.com>
 To: cytan299/tribahtinov <tribahtinov@noreply.github.com>
Cc: Subscribed <subscribed@noreply.github.com>
 Sent: Monday, June 19, 2017 6:59 AM
 Subject: [cytan299/tribahtinov] The pitch of the diffraction grating becomes thick (#4)

I noticed that the diffraction grating pitch generated by the webApps version tri-bahtinov mask generator is thicker than the conventional bahtinov mask generator on this site.According to the cloudy nights thread that that site refers to, the expression that determines the width (pitch) of the diffraction grating is explained as follows.
s = f / 150
Where s is the sum of slit and uncut space, f is focal length, 150 is bahtinov factor.According to the following part of generate.py,
spacing = (tri_stem_w + tri_w); -> Line 112, 217, 342
I interpreted that the variable equivalent to s is spacing, the variable equivalent to slit is tri_w, and the variable corresponding to uncut space is tri_stem_w.The formula for determining the width of the diffraction grating would be:
spacing = focal_length / BAHTINOV_FACTOROn the other hand, according to the following part of generate.py,
Tri_w = focal_length / BAHTINOV_FACTOR; -> Line 567
tri_w, rather than spacing, is generated by that expression. As a result, it seems that spacing is calculated to be large by tri_stem_w.I have not tested it because I can not prepare the python execution environment, but it might be able to fix it by doing as follows.567c567,572
< tri_w = focal_length/BAHTINOV_FACTOR;
---
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
—
You are receiving this because you are subscribed to this thread.
Reply to this email directly, view it on GitHub, or mute the thread.

satakagi, 2017-06-20:
Hi, cytan,
By the above patch, spacing (which is the sum of slit and uncut space) rather than tri_w (slit width) is calculated from BAHTINOV_FACTOR. As in the following equation
`spacing = focal_length / BAHTINOV_FACTOR;`
On the other hand, tri_stem_w (uncut space) was fixed at 0.2362 inches.
Therefore, when the spacing becomes smaller, the width of the slit (slot) becomes narrower.

So, I added an option to make tri_stem_w variable by specifying the ratio of the width of the slit and uncut space similar to that of the webApps I ported.

For the time being, I tested roughly this new patch by building a python execution environment on my PC.

<pre>
567c567,583
< tri_w = focal_length/BAHTINOV_FACTOR;
---
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
</pre>

cytan299, 2017-06-20:
Hi Satoru,   Thanks! Let me try it out again tonight.
cytan

      From: Satoru Takagi <notifications@github.com>
 To: cytan299/tribahtinov <tribahtinov@noreply.github.com>
Cc: cytan299 <cytan299@yahoo.com>; Comment <comment@noreply.github.com>
 Sent: Tuesday, June 20, 2017 9:26 AM
 Subject: Re: [cytan299/tribahtinov] The pitch of the diffraction grating becomes thick (#4)

Hi, cytan,
By the above patch, spacing (which is the sum of slit and uncut space) rather than tri_w (slit width) is calculated from BAHTINOV_FACTOR. As in the following equation
spacing = focal_length / BAHTINOV_FACTOR;
On the other hand, tri_stem_w (uncut space) was fixed at 0.2362 inches.
Therefore, when the spacing becomes smaller, the width of the slit (slot) becomes narrower.So, I added an option to make tri_stem_w variable by specifying the ratio of the width of the slit and uncut space similar to that of the webApps I ported.For the time being, I tested roughly this new patch by building a python execution environment on my PC.567c567,583
< tri_w = focal_length/BAHTINOV_FACTOR;
---
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
—
You are receiving this because you commented.
Reply to this email directly, view it on GitHub, or mute the thread.

cytan299, 2017-06-20:
Hi Satoru,   Thanks for the update. I think there's still something weird going on with the spacing/slit size when compared to the mask that is generated by astrojargon. Let me look at it over the weekend and then I will get back to you.
cytan

      From: Satoru Takagi <notifications@github.com>
 To: cytan299/tribahtinov <tribahtinov@noreply.github.com>
Cc: cytan299 <cytan299@yahoo.com>; Comment <comment@noreply.github.com>
 Sent: Tuesday, June 20, 2017 9:26 AM
 Subject: Re: [cytan299/tribahtinov] The pitch of the diffraction grating becomes thick (#4)
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
satakagi, 2017-06-22:
Hi, cytan,
In astrojargon, the width of slit and uncut space can always be set equal only, whereas patched generate.py and its webApps version have a richer function that can specify the width ratio.
On the other hand, I think that it would be preferable to be able to set the width of the "inner support" which is the stem between the center hole and the slits independently, considering the mechanical strength. And I think that it is appropriate that the value is about 0.2362 inch.
The draft of the patch is as follows.
<pre>
94a95
> tri_in_w = 0.2362*INCH2PIXELS; # inches, width of the inner support
567c568,589
< tri_w = focal_length/BAHTINOV_FACTOR;
---
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
584c606
< tri_in_r = tri_inb_r + tri_stem_w;
---
> tri_in_r = tri_inb_r + tri_in_w;
</pre>

cytan299, 2017-06-23:
Hi Satoru   Great job! I like it!
   I'll update the github distribution and credit you for the changes. I'll do it this weekend in case you have other improvements.
cytan

      From: Satoru Takagi <notifications@github.com>
 To: cytan299/tribahtinov <tribahtinov@noreply.github.com>
Cc: cytan299 <cytan299@yahoo.com>; Comment <comment@noreply.github.com>
 Sent: Thursday, June 22, 2017 12:53 PM
 Subject: Re: [cytan299/tribahtinov] The pitch of the diffraction grating becomes thick (#4)

Hi, cytan,
In astrojargon, the width of slit and uncut space can always be set equal only, whereas patched generate.py and its webApps version have a richer function that can specify the width ratio.
On the other hand, I think that it would be preferable to be able to set the width of the "inner support" which is the stem between the center hole and the slits independently, considering the mechanical strength. And I think that it is appropriate that the value is about 0.2362 inch.
The draft of the patch is as follows.94a95
> tri_in_w = 0.2362*INCH2PIXELS; # inches, width of the inner support
567c568,589
< tri_w = focal_length/BAHTINOV_FACTOR;
---
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
584c606
< tri_in_r = tri_inb_r + tri_stem_w;
---
> tri_in_r = tri_inb_r + tri_in_w;
—
You are receiving this because you commented.
Reply to this email directly, view it on GitHub, or mute the thread.

cytan299, 2017-06-26:
Hi Satoru,   I've updated the github site to acknowledge your contribution to generate.py in both README.md and the generate.py source code. See if you like it. 
cytan

      From: Satoru Takagi <notifications@github.com>
 To: cytan299/tribahtinov <tribahtinov@noreply.github.com>
Cc: cytan299 <cytan299@yahoo.com>; Comment <comment@noreply.github.com>
 Sent: Thursday, June 22, 2017 12:53 PM
 Subject: Re: [cytan299/tribahtinov] The pitch of the diffraction grating becomes thick (#4)

Hi, cytan,
In astrojargon, the width of slit and uncut space can always be set equal only, whereas patched generate.py and its webApps version have a richer function that can specify the width ratio.
On the other hand, I think that it would be preferable to be able to set the width of the "inner support" which is the stem between the center hole and the slits independently, considering the mechanical strength. And I think that it is appropriate that the value is about 0.2362 inch.
The draft of the patch is as follows.94a95
> tri_in_w = 0.2362*INCH2PIXELS; # inches, width of the inner support
567c568,589
< tri_w = focal_length/BAHTINOV_FACTOR;
---
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
584c606
< tri_in_r = tri_inb_r + tri_stem_w;
---
> tri_in_r = tri_inb_r + tri_in_w;
—
You are receiving this because you commented.
Reply to this email directly, view it on GitHub, or mute the thread.

satakagi, 2017-06-28:
Thank you for your good work. I am porting a routine implemented in webApps to generate.py to determine a split point so that the area of the slots of right up and right down are equal. It takes a bit of time, but I will report it as a new issue or pull request once it is completed.

Closed 2017-07-17.

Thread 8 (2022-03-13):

tri-bahtinov mask to collimate HyperStar lens

skyjak, 2022-03-13:
Hi, I was wondering if in order to collimate a HyperStar lens the tri-Bahtinov mask should be made for the shorter focal length (f/2) instead of the regular one for f/10?  I guess the number of slots optimal for f/2 will be different than for f/10, correct?  If this is so, do you know who can 3D-print this f/2 TriBahtinov mask? Thanks!

cytan299, 2022-03-13:
Sorry, I have no idea. I don't have hyperstar. I'd suggest asking on the Cats/Casses forum on cloudynights. People there have used the TriBahtinov for collimating f/2 systems.

skyjak, 2022-03-14:
OK, thanks.

Closed 2022-08-26.

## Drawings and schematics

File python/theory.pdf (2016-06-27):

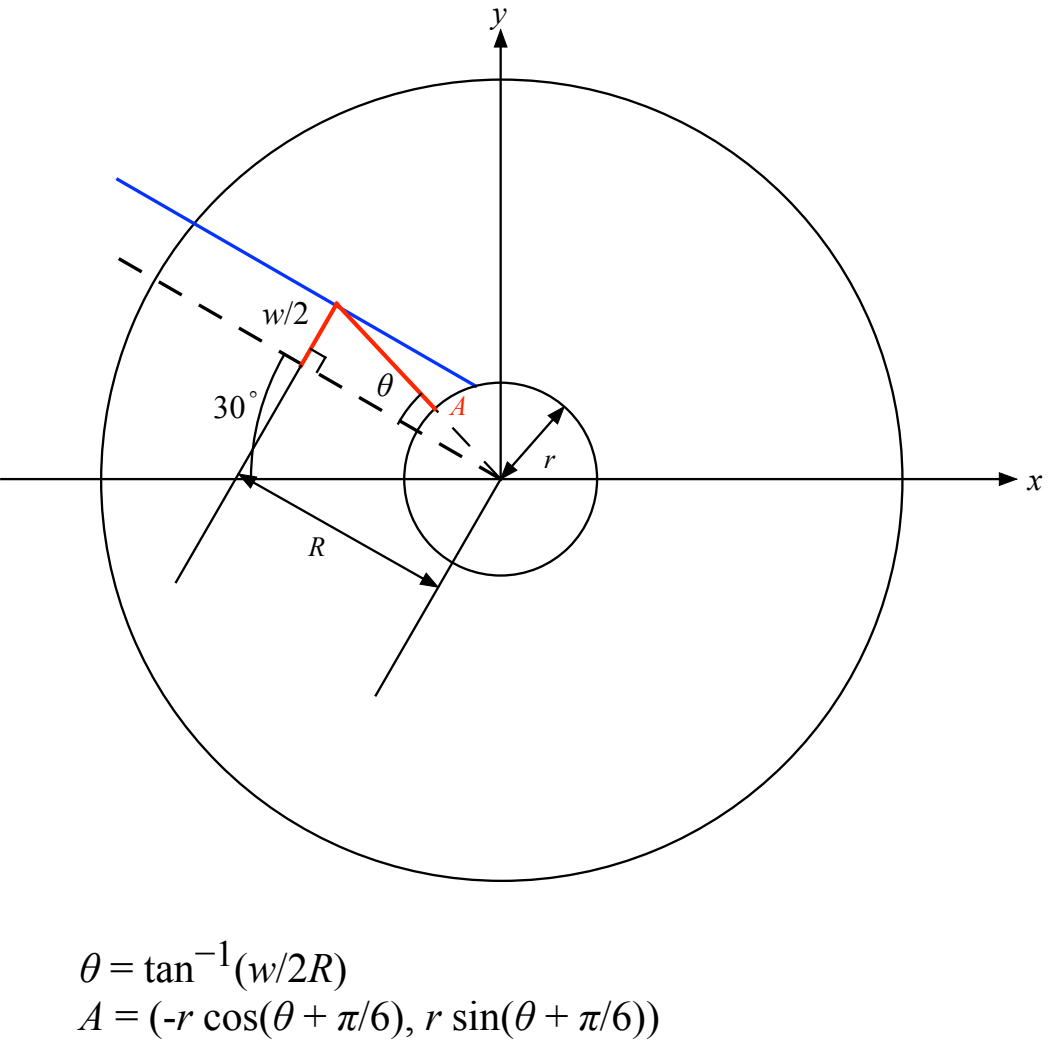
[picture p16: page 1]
θ = tan⁻¹(w/2R) A = (-r cos(θ + π/6), r sin(θ + π/6))

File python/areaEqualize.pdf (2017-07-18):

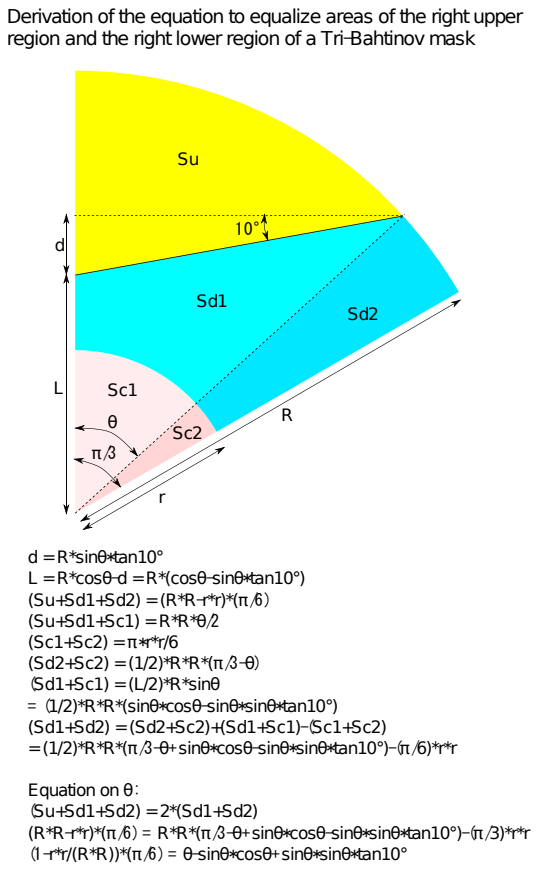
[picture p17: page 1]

Derivation of the equation to equalize areas of the right upper
region and the right lower region of a Tri-Bahtinov mask

d = R*sinθ*tan10°
L = R*cosθ-d = R*(cosθ-sinθ*tan10°)
(Sd1+Sc1) = (L/2)*R*sinθ
= (1/2)*R*R*(sinθ*cosθ-sinθ*sinθ*tan10°)
= (1/2)*R*R*(π/3-θ+sinθ*cosθ-sinθ*sinθ*tan10°)-(π/6)*r*r

Equation on θ:
(R*R-r*r)*(π/6) = R*R*(π/3-θ+sinθ*cosθ-sinθ*sinθ*tan10°)-(π/3)*r*r
(1-r*r/(R*R))*(π/6) = θ-sinθ*cosθ+sinθ*sinθ*tan10°

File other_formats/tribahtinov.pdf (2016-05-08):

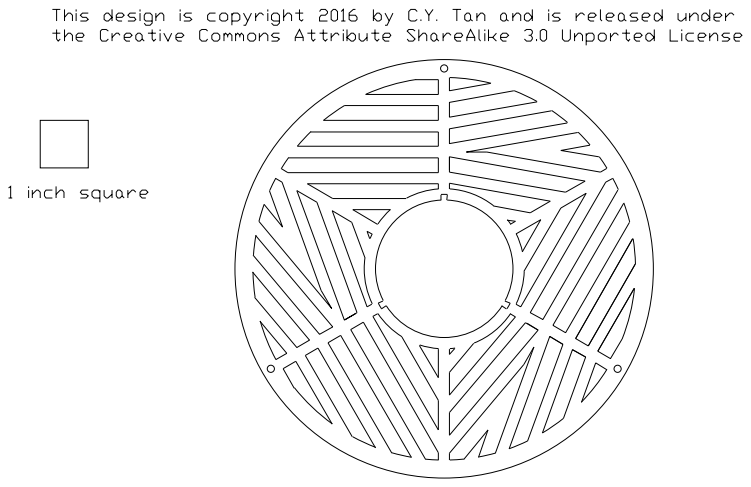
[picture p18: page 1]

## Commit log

2016-05-08 Modified README.md's. Added maskulator_movie and other_formats directories
    [tribahtinov.dwg, tribahtinov.dxf]
2018-12-30 pre-made/ETX125 mask: Improved this mask by adding more slots. This gives a better diffraction pattern than the previous version
2019-01-15 pre-made: added c11.stl
    [c11.stl]
2019-01-15 pre-made/c11.stl: Fixed problem with bad render of one slit
    [c11.stl]
2019-03-27 pre-made/README.md: Added description of c11.stl
